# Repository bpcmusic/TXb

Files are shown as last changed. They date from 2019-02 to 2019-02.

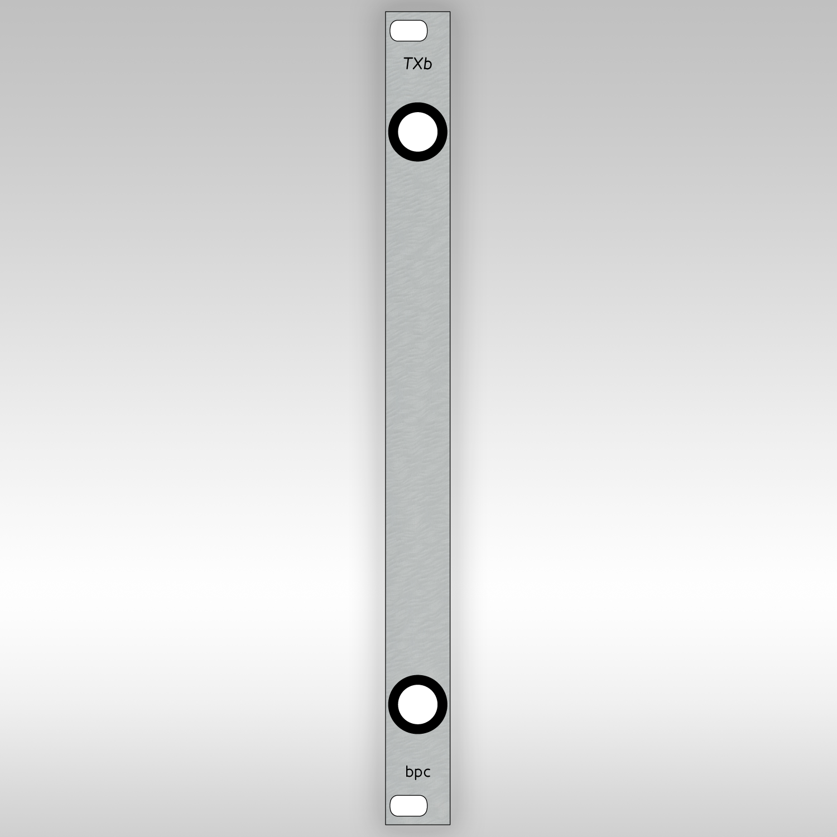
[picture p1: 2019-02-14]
panel/TXb_lg.png

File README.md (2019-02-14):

# TXb - 2HP i2c Bus Board w/ 3.5mm Connectors

The TELEXb (TXb) is a 2HP powered bus board for the i2c ecosystem that also enables the connection of external devices using the two 3.5mm stereo jacks at the top and the bottom of the module. These jacks can be used for connection to the 16n FaderBank, TXb that are in disconnected rack rows, or to fiendishly wonderful Frankenstein machines of your own creation.

TXn

## High-Level i2c Tips

There are some key things to keep in mind with the TXb (and i2c busses in general):

- Powered bus boards are required when you connect three or more devices to your Teletype via i2c.
- You should only have one bus board connected to power at a time.
- Connections should be kept as short as possible using high-quality cabling (less than 3.5mm).
- There still are practical limits to having a stable i2c bus that are highly dependent on the topology of your deployment. Plan for some trial and error.

Want more help understanding what i2c can and can't do and how to use it in your setup? Check out this awesome [User's Guide to i2c](https://llllllll.co/t/a-users-guide-to-i2c/19219) that was put together by some awesome people.

## Module Specifications

- +12V: 1 mA 
- -12V: 0 mA
- +5V: 0 mA
- 2HP
- 20.5mm Depth

## Folders & Files Explained

* **assistive**: 
	* ```TXb Frame``` - a 3D printed frame to hold multiple TXb at a time
	* ```TXb Stencil Frame``` - a 3D printed stencil frame to hold the TXb in place while applying solder paste
	* ```TXb Stencil.svg``` - the solder paste stencil for laser cutting
	
* **board**
	* ```gerbers``` - the gerbers files (and Eagle files) for the PCB
	* ```images``` - image rederings of the PCB
	* ```TELEXb_v1.2.brd/sch``` - the master Eagle file for the TXb
	
* **extras**
	* ```instructions.docx``` - the instructions delivered with the pre-built module
	
* **panel**
	* ```metalphoto``` - the individual files used for the creation of the metalphoto panel in the retail version
	* ```TXb.ai/svg``` - the panel files
	* ```TXb_lasercut.svg``` - the file used for cutting prototype panels out of acrylic
	* ```TXb_lg.png``` - a big version of the panel
	* ```TXb_mp.zip``` - the archive sent for fabrication
	* ```TXb_sm.png``` - a small photo of the panel

* ```TXb BOM.csv``` - the BOM for this version of the TXb.

## Links

Visit the TXb on Modular Grid:

* [Modular Grid](https://www.modulargrid.net/e/other-unknown-telexb)

Pre-built TXb are occasionally made availalbe for purchase here:

* [store.bpcmusic.com](https://store.bpcmusic.com/products/telexb)

## License

[CC BY-SA 4.0](http://creativecommons.org/licenses/by-sa/4.0/)

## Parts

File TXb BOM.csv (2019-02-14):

Quantity | Part | Description | Mfg Id | DigiKey | Other
6 | 2x3 Headers | CONN HEADER VERT 6POS 2.54MM | 609-3218-ND | 67996-406HLF
1 | Voltage Regulator | IC REG LINEAR 3.3V 800MA SOT223 | AZ1117CH-3.3TRG1DICT-ND | AZ1117CH-3.3TRG1
2 | Resistors | RES SMD 2.2K OHM 1% 1/4W 1206 | 541-2.20KFTR-ND | CRCW12062K20FKEA
1 | Shrouded Power Header | CONN HEADER VERT 10POS 2.54MM | 302-S101 | ED1543-ND
2 | Stereo Thonk Jacks | STEREO THONKICONN JACKS 3.5mm | PJ366ST | - | https://www.thonk.co.uk/shop/3-5mm-jacks/

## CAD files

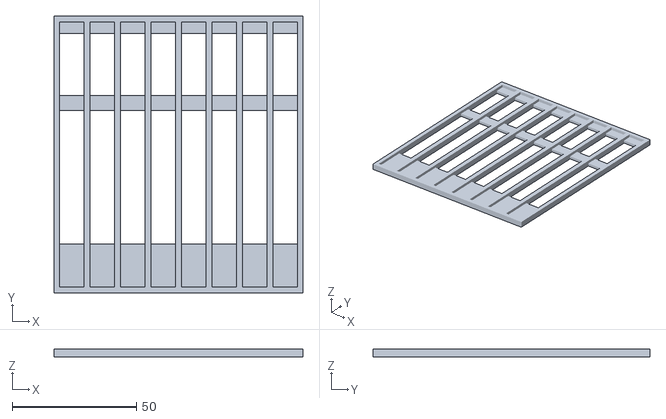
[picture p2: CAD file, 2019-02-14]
assistive/TXb Frame.stl
100.4 x 111.5 x 3.20

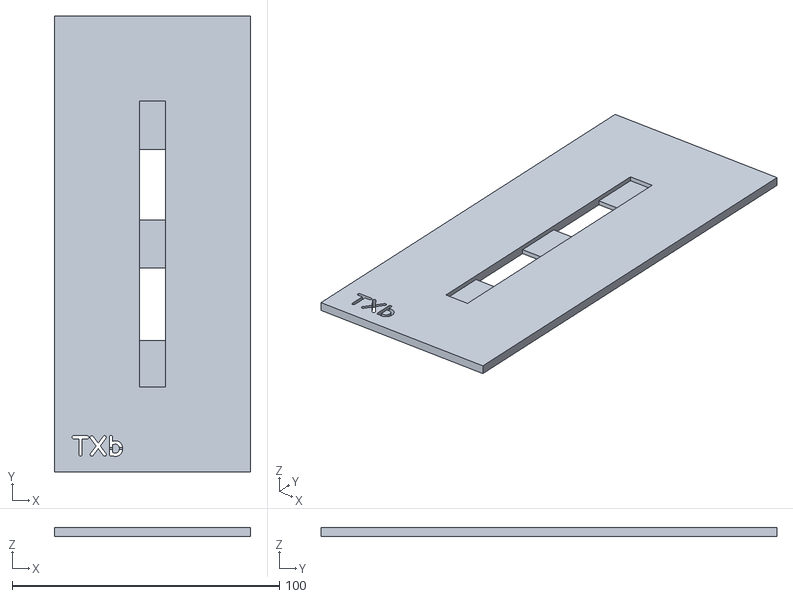
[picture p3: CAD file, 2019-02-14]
assistive/TXb Stencil Frame.stl
73.3 x 170.5 x 3.20

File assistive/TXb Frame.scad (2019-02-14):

$fn = 50;

// TXn Top

// framex = 250;


tolerance = .5;

pcbX = 9.3;
pcbY = 106.5;
pcbZ = 1.6;

frame = 2.5;

framex = pcbX + frame;

barOneStart = 0;
barOneEnd = 18;

barTwoStart = 71;
barTwoEnd = 77;

barThreeStart = 102;
barThreeEnd = 107.01 + (tolerance / 2);

corner = 2.5;

for (a =[0:7]) frame(a * (framex + .5));


module frame(xOrigin){

    union(){
        
        difference() {
            translate([xOrigin-frame, - frame, 0])
                cube([pcbX + 2 * frame, pcbY + 2 * frame, 2 * pcbZ]);
            translate([xOrigin-tolerance/2, -tolerance/2, 0])
                cube([pcbX + tolerance, pcbY + tolerance, 2 * pcbZ]);
        }

        translate([xOrigin-tolerance/2, barOneStart-(tolerance/2), 0])
            cube([pcbX + tolerance, barOneEnd - barOneStart -tolerance, pcbZ]);
            
        translate([xOrigin-tolerance/2, barTwoStart, 0])
            cube([pcbX + tolerance, barTwoEnd - barTwoStart, pcbZ]);
        
        translate([xOrigin-tolerance/2, barThreeStart, 0])
            cube([pcbX + tolerance, barThreeEnd - barThreeStart, pcbZ]);

    }
 
 }

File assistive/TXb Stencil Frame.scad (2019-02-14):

$fn = 50;

// TXo Bottom

tolerance = .5;

pcbX = 9.3;
pcbY = 106.5;
pcbZ = 1.6;

frame = 32;

barOneStart = 0;
barOneEnd = 18;

barTwoStart = pcbY / 2 - 9;
barTwoEnd = barTwoStart + 18;

barThreeStart = pcbY - 18;
barThreeEnd = 107.01 + (tolerance / 2);

corner = 2.5;

difference(){

    union(){
        difference() {
            translate([-frame, - frame, 0])
                cube([pcbX + 2 * frame, pcbY + 2 * frame, 2 * pcbZ]);
            translate([-tolerance/2, -tolerance/2, 0])
                cube([pcbX + tolerance, pcbY + tolerance, 2 * pcbZ]);
        }

        translate([-tolerance/2, barOneStart-(tolerance/2), 0])
            cube([pcbX + tolerance, barOneEnd - barOneStart -tolerance, pcbZ]);
            
        translate([-tolerance/2, barTwoStart, 0])
            cube([pcbX + tolerance, barTwoEnd - barTwoStart, pcbZ]);
        
        translate([-tolerance/2, barThreeStart, 0])
            cube([pcbX + tolerance, barThreeEnd - barThreeStart, pcbZ]);

    }

     translate([-frame * .8, -frame * .8]) {
       linear_extrude(height = 2 * pcbZ)
        text("TXb", font = "Core Humanist Sans:style=Bold", size = 8);
     }
 
 }

    translate([-14, (-frame * .8) + 2])
        cube([12, .8, pcbZ]);

/*

translate([-13,-frame * .74,0])
    cube([10, pcbZ * .5, pcbZ / 3]);


translate([-4,-frame * .655,0])
    cube([8, pcbZ * .4, pcbZ / 3]);
 
translate([-4,-frame * .755,0])
    cube([7, pcbZ * .4, pcbZ / 3]);

translate([3,-frame * .74,0])
    cube([7, pcbZ * .4, pcbZ / 3]);
 
translate([18,-frame * .74,0])
    cube([7, pcbZ * .4, pcbZ / 3]);
 
 */               

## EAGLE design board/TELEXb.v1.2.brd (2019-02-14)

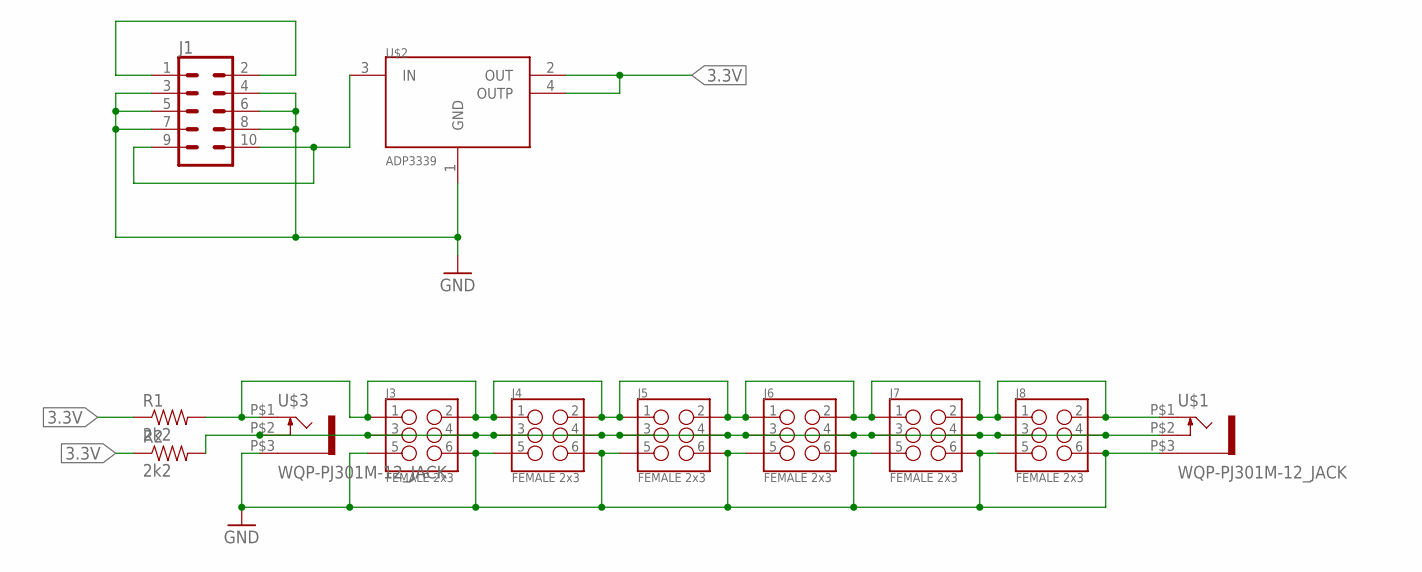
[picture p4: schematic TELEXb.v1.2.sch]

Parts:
J1: CONN_05X2SHD; 2X5-SHROUDED
J3, J4, J5, J6, J7, J8: FEMALE 2x3; 2X3
R1, R2: 2k2; 1206
U$1, U$3: WQP-PJ301M-12_JACK
U$2: ADP3339; SOT223

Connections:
3.3V: R1.1, R2.1, U$2.2 (OUT), U$2.4 (OUTP)
GND: J1.3, J1.4, J1.5, J1.6, J1.7, J1.8, J3.5, J3.6, J4.5, J4.6, J5.5, J5.6, J6.5, J6.6, J7.5, J7.6, J8.5, J8.6, U$1.P$3 (1), U$2.1 (GND), U$3.P$3 (1)
unnamed: J1.9, J1.10, U$2.3 (IN)
unnamed: J3.1, J3.2, J4.1, J4.2, J5.1, J5.2, J6.1, J6.2, J7.1, J7.2, J8.1, J8.2, R1.2, U$1.P$1 (2), U$3.P$1 (2)
unnamed: J1.1, J1.2
unnamed: J3.3, J3.4, J4.3, J4.4, J5.3, J5.4, J6.3, J6.4, J7.3, J7.4, J8.3, J8.4, R2.2, U$1.P$2 (3), U$3.P$2 (3)

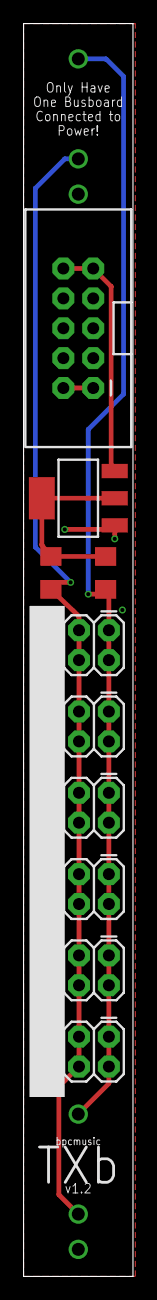
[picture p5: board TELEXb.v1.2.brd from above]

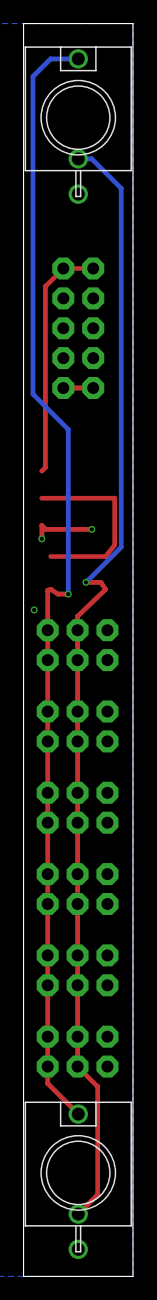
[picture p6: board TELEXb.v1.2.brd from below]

Board: 2 copper layers, 9.3 x 106.5 mm, 12 parts (2 on the bottom side), 6 nets.

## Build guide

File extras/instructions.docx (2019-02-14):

Let’s be honest: you aren’t going to read me. I’ve probably unceremoniously fallen to the floor, brushed aside like navel lint as you unboxed your TELEXb (TXb). I bet your cat is sitting on me right now as you are trying to figure out how to use the thing that I’m here to help you with. Well, it is hard to help you when I am being literally smothered by cat-ass! You try it sometime. (In case you actually did decide to read this, sorry about the cat-ass stuff. I get a little moody.)

Look, even if you are reading this, I know with every fiber of my being that you would rather not. So, to that end, I’ll keep it short. Let’s start with an assumption that we both can agree on: you purchased this TXb to connect an i2c bus of some sort. Why do I assume that? Because that is all it really does. I won’t bother explaining i2c and why you would need this thing. That would waste of both of our time – not to mention the cat’s. Let’s just get on with the information.

Things You Should Know about Your TXb (in No Particular Order)

1. If your i2c bus has multiple bus boards for distribution purposes, only connect one of them to power at any given time.
2. If you have more than one TXb on your bus, make sure that only one of them is connected to power. I know this is redundant; just want to make sure you got it.
3. You might not need to power the TXb if you have a newer Teletype as the latest board revision natively supplies more “pull-up” to the i2c bus.
4. For best results, keep your i2c runs as short as possible. Long runs can destabilize your bus. How long? I knew you would ask that. It is hard to say. It is all dependent on the types of cables you use, how long they are, and how many modules you connect to your bus. You clearly can hook a bunch of stuff to your bus; just be smart and willing to experiment in order to find what works for your topology.
5. Do not hot-plug your modules to the i2c bus. Always have the power turned off when connecting and/or disconnecting things.
6. Do not allow any other voltage sources to short out to the bus’s i2c pins. You can severely damage your instruments if you let the higher voltages in your case pollute the bus. (I’ve seen it happen and still have nightmares – though they will most likely be eclipsed by the feline full moon I just experienced. Thanks for that.)
7. The front panel i2c connections are guarded by the 3D printed dust caps. Please take care when you remove them from the module so as not to snap them off in the jacks. It would suck for you to have to fish that little plastic piece out. Really.
8. Put the jack caps back in the i2c connections when they aren’t in use. Accidental patching of hostile high voltage (audio/CV/triggers) can damage your modules.
9. When connecting a 16n or second TXb to one of the jacks on the front, use short, high quality, STEREO cables. Mono cables cause problems and (potentially) can damage your instruments.
10. Do not hot-plug the jacks on the front. There is a chance you will fry things if you do and it will not be my fault! I’ve given you (and your cat’s ass) fair warning.
11. Have fun and good luck. The TXb is easy to use properly; don’t get freaked out.

Let’s be honest: you aren’t going to read me. I’ve probably unceremoniously fallen to the floor, brushed aside like navel lint as you unboxed your TELEXb (TXb). I bet your cat is sitting on me right now as you are trying to figure out how to use the thing that I’m here to help you with. Well, it is hard to help you when I am being literally smothered by cat-ass! You try it sometime. (In case you actually did decide to read this, sorry about the cat-ass stuff. I get a little moody.)

Look, even if you are reading this, I know with every fiber of my being that you would rather not. So, to that end, I’ll keep it short. Let’s start with an assumption that we both can agree on: you purchased this TXb to connect an i2c bus of some sort. Why do I assume that? Because that is all it really does. I won’t bother explaining i2c and why you would need this thing. That would waste of both of our time – not to mention the cat’s. Let’s just get on with the information.

Things You Should Know about Your TXb (in No Particular Order)

12. If your i2c bus has multiple bus boards for distribution purposes, only connect one of them to power at any given time.
13. If you have more than one TXb on your bus, make sure that only one of them is connected to power. I know this is redundant; just want to make sure you got it.
14. You might not need to power the TXb if you have a newer Teletype as the latest board revision natively supplies more “pull-up” to the i2c bus.
15. For best results, keep your i2c runs as short as possible. Long runs can destabilize your bus. How long? I knew you would ask that. It is hard to say. It is all dependent on the types of cables you use, how long they are, and how many modules you connect to your bus. You clearly can hook a bunch of stuff to your bus; just be smart and willing to experiment in order to find what works for your topology.
16. Do not hot-plug your modules to the i2c bus. Always have the power turned off when connecting and/or disconnecting things.
17. Do not allow any other voltage sources to short out to the bus’s i2c pins. You can severely damage your instruments if you let the higher voltages in your case pollute the bus. (I’ve seen it happen and still have nightmares – though they will most likely be eclipsed by the feline full moon I just experienced. Thanks for that.)
18. The front panel i2c connections are guarded by the 3D printed dust caps. Please take care when you remove them from the module so as not to snap them off in the jacks. It would suck for you to have to fish that little plastic piece out. Really.
19. Put the jack caps back in the i2c connections when they aren’t in use. Accidental patching of hostile high voltage (audio/CV/triggers) can damage your modules.
20. When connecting a 16n or second TXb to one of the jacks on the front, use short, high quality, STEREO cables. Mono cables cause problems and (potentially) can damage your instruments.
21. Do not hot-plug the jacks on the front. There is a chance you will fry things if you do and it will not be my fault! I’ve given you (and your cat’s ass) fair warning.
22. Have fun and good luck. The TXb is easy to use properly; don’t get freaked out.

TELEXb TIPS

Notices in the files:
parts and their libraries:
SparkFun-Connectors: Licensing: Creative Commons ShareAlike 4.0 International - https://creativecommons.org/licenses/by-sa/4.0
